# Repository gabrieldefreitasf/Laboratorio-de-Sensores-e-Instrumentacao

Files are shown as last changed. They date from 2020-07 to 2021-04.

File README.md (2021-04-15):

# Laboratorio-de-Sensores-e-Instrumentacao(LSI)
Repositório para códigos e arquivos de projeto referentes ao reflectômetro automatizado.<br>
Aqui estão códigos para ESP32 DevKit V1 escritos em framework Arduino para módulo de aquisição e controle do reflectômetro automatizado do LSI.<br>
Estão aqui os códigos separados por aquisição, movimento 2D, rotação e emulador para envio de dados.
Um código em python denominado ESP 32 - Datalogger é utilizado para gerar um arquivo com dados provenientes da serial.<br>
**Projeto desenvolvido no Laboratório de Sensores e Instrumentação do Departamento de Eletrônica e Sistemas da UFPE.**<br>
<br>
<br>
**Laboratory of Sensors and Instrumentation**<br>
Repository for codes and design files for the automated reflectometer.<br>
Here are the codes for ESP32 written in Arduino framework for LSI's automated reflectometer acquisition and control module.<br>
The codes are separated by acquisition, 2D movement, rotation and an emulator, for sending simulated data.<br>
A python code called ESP 32 - Datalogger is used to generate a file with data from the serial.<br>
**Project developed in the Laboratory of Sensors and Instrumentation under the Department of Electronics and Systems from UFPE.**<br>
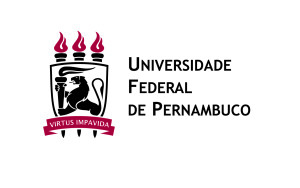
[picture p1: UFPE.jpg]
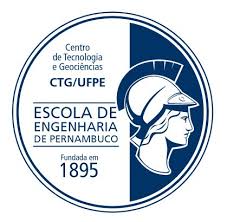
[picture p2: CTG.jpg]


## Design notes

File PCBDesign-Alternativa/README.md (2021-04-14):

Este diretório abriga os arquivos de projeto para placa de circuito impresso do reflectômetro automatizado. Os arquivos foram gerados em plataforma KiCAD.
--------------------------------
This directory contains the design files for the printed circuit board for the automated reflectometer. The files were generated on KiCAD platform.

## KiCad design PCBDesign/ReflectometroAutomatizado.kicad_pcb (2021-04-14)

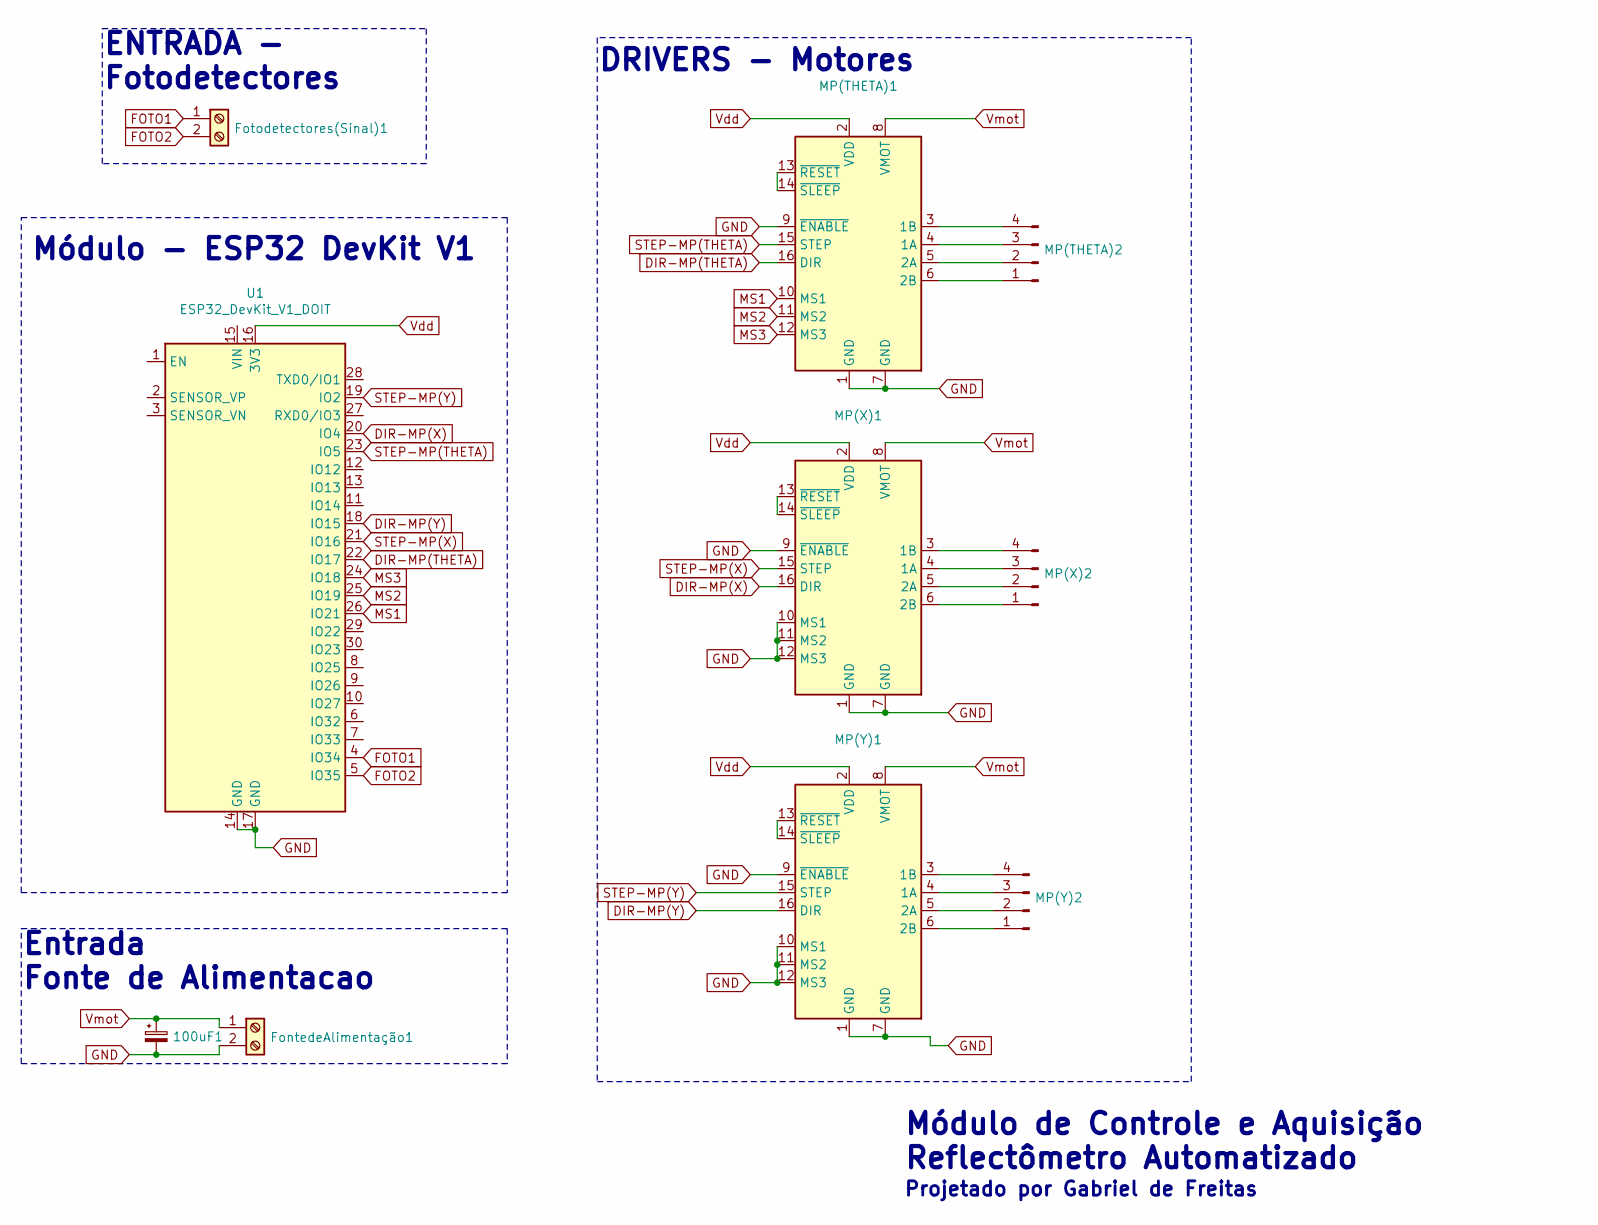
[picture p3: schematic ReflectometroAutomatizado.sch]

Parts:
100uF1: CP_Small; CP_Radial_D5.0mm_P2.00mm
FontedeAlimentação1: Screw_Terminal_01x02; TerminalBlock_bornier-2_P5.08mm
Fotodetectores(Sinal)1: Screw_Terminal_01x02; TerminalBlock_bornier-2_P5.08mm
MP(THETA)1: Pololu_Breakout_A4988; MODULE_A4988
MP(THETA)2: Conn_01x04_Male; PinHeader_1x04_P2.54mm_Vertical
MP(X)1: Pololu_Breakout_A4988; MODULE_A4988
MP(X)2: Conn_01x04_Male; PinHeader_1x04_P2.54mm_Vertical
MP(Y)1: Pololu_Breakout_A4988; MODULE_A4988
MP(Y)2: Conn_01x04_Male; PinHeader_1x04_P2.54mm_Vertical
U1: ESP32_DevKit_V1_DOIT; esp32_devkit_v1_doit

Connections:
DIR-MP(THETA): MP(THETA)1.16 (DIR), U1.22 (IO17)
DIR-MP(X): MP(X)1.16 (DIR), U1.20 (IO4)
DIR-MP(Y): MP(Y)1.16 (DIR), U1.18 (IO15)
FOTO1: Fotodetectores(Sinal)1.1, U1.4 (IO34)
FOTO2: Fotodetectores(Sinal)1.2, U1.5 (IO35)
GND: 100uF1.2, FontedeAlimentação1.2, MP(THETA)1.1 (GND), MP(THETA)1.7 (GND), MP(THETA)1.9 (~ENABLE), MP(X)1.1 (GND), MP(X)1.7 (GND), MP(X)1.9 (~ENABLE), MP(X)1.10 (MS1), MP(X)1.11 (MS2), MP(X)1.12 (MS3), MP(Y)1.1 (GND), MP(Y)1.7 (GND), MP(Y)1.9 (~ENABLE), MP(Y)1.10 (MS1), MP(Y)1.11 (MS2), MP(Y)1.12 (MS3), U1.14 (GND), U1.17 (GND)
MS1: MP(THETA)1.10 (MS1), U1.26 (IO21)
MS2: MP(THETA)1.11 (MS2), U1.25 (IO19)
MS3: MP(THETA)1.12 (MS3), U1.24 (IO18)
unnamed: MP(THETA)1.3 (1B), MP(THETA)2.4
unnamed: MP(THETA)1.4 (1A), MP(THETA)2.3
unnamed: MP(THETA)1.5 (2A), MP(THETA)2.2
unnamed: MP(THETA)1.6 (2B), MP(THETA)2.1
unnamed: MP(THETA)1.13 (~RESET), MP(THETA)1.14 (~SLEEP)
unnamed: MP(X)1.3 (1B), MP(X)2.4
unnamed: MP(X)1.4 (1A), MP(X)2.3
unnamed: MP(X)1.5 (2A), MP(X)2.2
unnamed: MP(X)1.6 (2B), MP(X)2.1
unnamed: MP(X)1.13 (~RESET), MP(X)1.14 (~SLEEP)
unnamed: MP(Y)1.3 (1B), MP(Y)2.4
unnamed: MP(Y)1.4 (1A), MP(Y)2.3
unnamed: MP(Y)1.5 (2A), MP(Y)2.2
unnamed: MP(Y)1.6 (2B), MP(Y)2.1
unnamed: MP(Y)1.13 (~RESET), MP(Y)1.14 (~SLEEP)
STEP-MP(THETA): MP(THETA)1.15 (STEP), U1.23 (IO5)
STEP-MP(X): MP(X)1.15 (STEP), U1.21 (IO16)
STEP-MP(Y): MP(Y)1.15 (STEP), U1.19 (IO2)
Vdd: MP(THETA)1.2 (VDD), MP(X)1.2 (VDD), MP(Y)1.2 (VDD), U1.16 (3V3)
Vmot: 100uF1.1, FontedeAlimentação1.1, MP(THETA)1.8 (VMOT), MP(X)1.8 (VMOT), MP(Y)1.8 (VMOT)

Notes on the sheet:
DRIVERS - Motores
ENTRADA - Fotodetectores
Módulo - ESP32 DevKit V1
Entrada Fonte de Alimentacao
Módulo de Controle e Aquisição Reflectômetro Automatizado
Projetado por Gabriel de Freitas

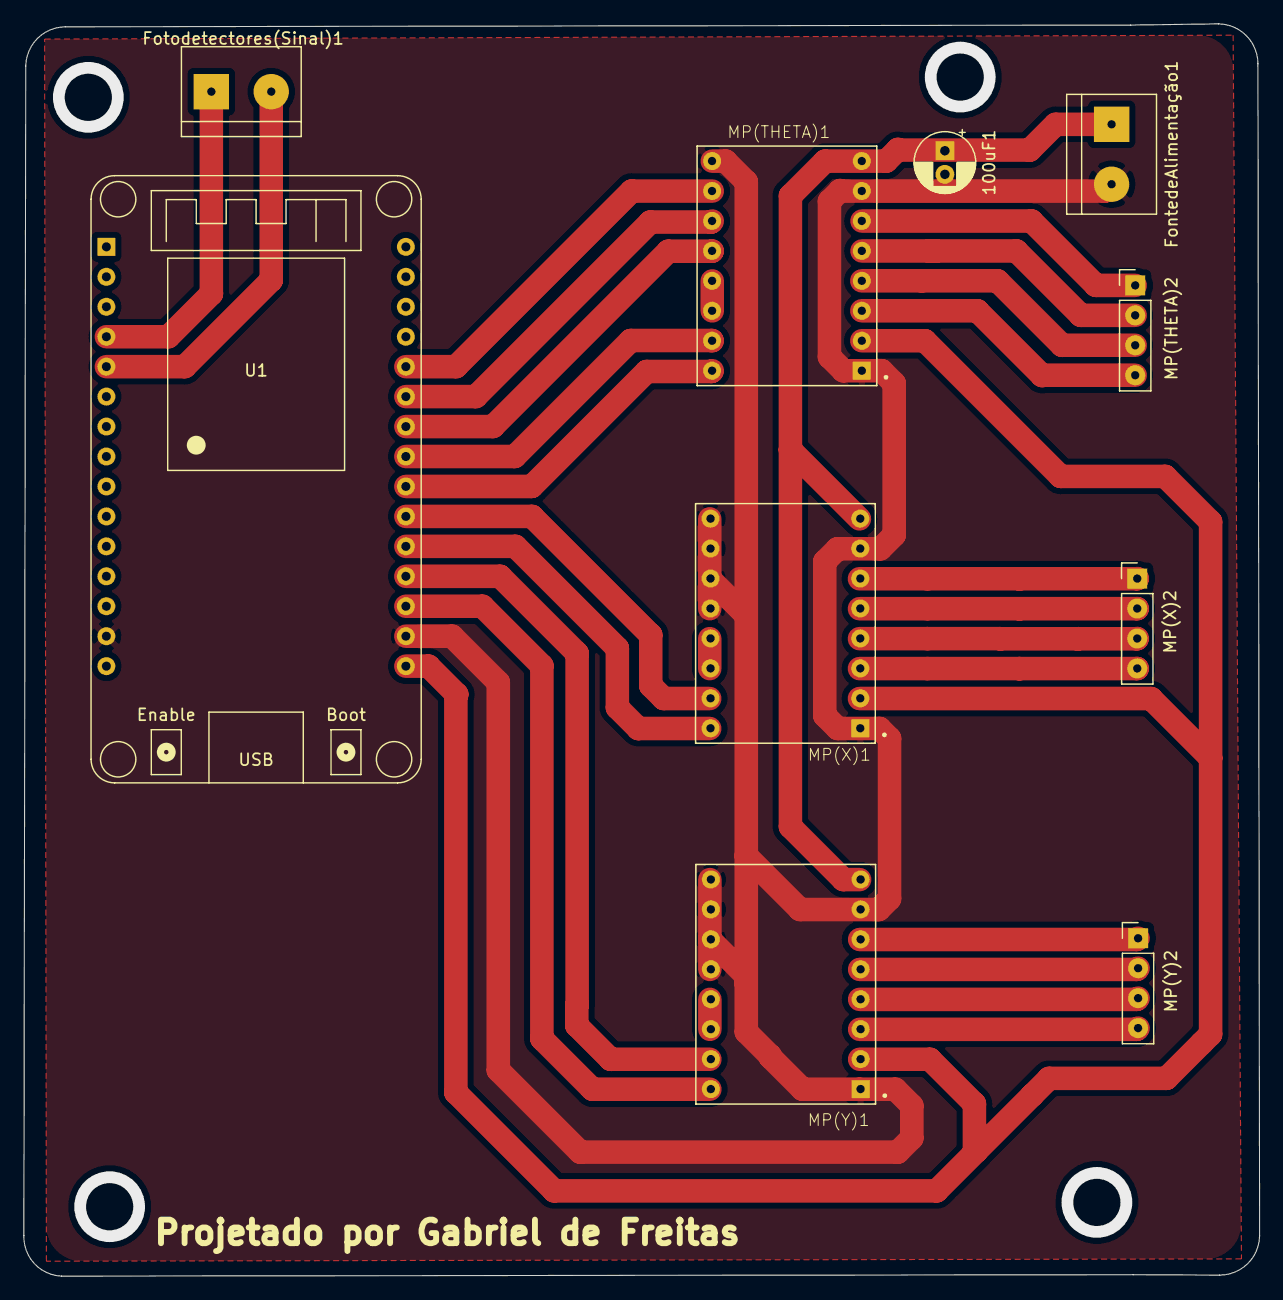
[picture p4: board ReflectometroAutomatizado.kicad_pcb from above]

Board: 2 copper layers, 104.8 x 106.2 mm, 10 parts (0 on the bottom side), 29 nets.

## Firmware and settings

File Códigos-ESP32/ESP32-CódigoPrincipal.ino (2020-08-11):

//Aquisição+Rotação+Movimento 2D - Código para ESP32, controle baseado em driver a4988
//Laboratório de Sensores e Instrumentação - Grupo de Fotônica - UFPE
//Gabriel de Freitas
//OBS: 6.163° / revolução. 1 passo rotaciona 0.061°
//OBS2: 0.011mm/passo
//OBS3: Cálculos executados são desenvolvidos no artigo: "Maintaining a stationary laser footprint during angular scan in internal-reflection experiments" - E. Fontana
//---------------------------------------------------
#include <math.h>
const int stepPin = 5;                               // Passo e direção para motor de movimento angular
const int dirPin = 17;
const int stepPinx = 16;
const int dirPinx = 4;
const int stepPiny = 2;
const int dirPiny = 15;
const int MS1 = 21;
const int MS2 = 19;
const int MS3 = 18;
// Declaração de Entradas Analógicas
const int foto1 = 34;                                   // Fotodetector de referência é conectado ao GPIO 34 (Analog ADC1_CH6)
const int foto2 = 35;                                   // Fotodetector de saída é conectado ao GPIO 35 (Analog ADC1_CH7)
//Fim das entradas analógicas
//Variáveis para aquisição de dados
int ValorFoto1 = 0;                                   //Variável para fotodetector de referência (foto1)
int ValorFoto2 = 0;                                   //Variável para fotodetector de saída (foto2)
int N;                                                //Número de médias para obtenção de um ponto na curva de reflectância
float R = 0;                                          //Valor médio de reflectância (Será plotado no gráfico)
float soma = 0;                                       //Variável auxiliar para cálculo de média
float reflect[2];                                     //Vetor para armazenar valores adquiridos de reflectância(Tem que ter o tamanho de N)
//Fim das variáveis para aquisição de dados
float pi = 3.14159;
// Definição de parâmetros do prisma
float alpha = pi/3;                                     //Ângulo em rad
float beta = pi/3;
float gama = pi/3;
float w = 0;                                            //Posição atual do feixe na face superior do prisma, inicialmente 0
float a = 50;                                           //Dimensões do prisma (em mm)
float b = 50;
float c = 50;
float n = 1.5;                                          //Índice de refração do prisma
//Fim da definição de parâmetros do prisma
//Definições de variáveis úteis para correção da posição do feixe (Proveniente do artigo)
float theta = 6;                                      //Ângulo a ser rotacionado
float theta_atual;                                      //Ângulo que o sistema está, essa variável vai ser usada para plotar o gráfico.
float l;                                                //Variável auxiliar no cálculo (pode ser excluída depois)
float d;                                                //Distância necessária transladar para manter feixe no mesmo ponto
float theta_r;                                          //Ângulo refratado. Útil no cálculo de d
float r;                                                //Raio da circunferência inscrita
//Fim das definições de variáveis
//Definição de variáveis para movimentação 2D
float esp = 2;                                     // Espaçamento entre células em mm
float x,y = 0;                                     // Posição em x e y em mm, sempre inicia-se em (0,0)
int celula;                                        // Célula que o reflectômetro deve se posicionar, receber valo de 0 a 120 do usuário
//Fim da definição de variáveis para movimentação 2D

void setup() 
{
  Serial.begin(115200);
  analogReadResolution(12);                             //Número de bits do ADC
  adcAttachPin(34);                                     //Selecionando pino 34 para ADC
  adcAttachPin(35);                                     //Selecionando pino 35 para ADC
  analogSetSamples(1);                                  //Selecionando número de amostras
  analogSetPinAttenuation(34,ADC_0db);                  //Seleciona atenuação de 0db no pino 34
  analogSetPinAttenuation(35,ADC_0db);                  //Seleciona atenuação de 0db no pino 35
  pinMode(5, OUTPUT);
  pinMode(17, OUTPUT);
  pinMode(16, OUTPUT);
  pinMode(4, OUTPUT);
  pinMode(2, OUTPUT);
  pinMode(15, OUTPUT);
  pinMode(21, OUTPUT);
  pinMode(19, OUTPUT);
  pinMode(18, OUTPUT);
  pinMode(34, INTPUT);
  pinMode(35, INTPUT);
}

void adquirir()                                         //Adquire um ponto de reflectância a partir de média de N pontos. 
{
  for (int i=0; i<N; i++)
  {
  ValorFoto1 = analogRead(foto1);                       //Lê valor do fotodetector de REFERÊNCIA
  adcBusy(34);                                          //Verifica se está ocorrendo conversão no pino 34, esse comando retorna verdadeiro ou falso
  ValorFoto2 = analogRead(foto2);                       //Lê valor do fotodetector de SAÍDA
  adcBusy(35);                                          //Verifica se está ocorrendo conversão no pino 34, esse comando retorna verdadeiro ou falso
  reflect[i] = ValorFoto2/ValorFoto1;
  soma = soma+ reflect[i];
  }
  R = soma/N;
  delayMicroseconds(500);
}

void rotacionar (float theta)
{
  if (theta<0){                                         //Verifica para qual lado deve rotacionar
  digitalWrite(dirPin, HIGH);                           //Rotaciona para região negativa(Esquerda)
  }
  else{
    digitalWrite(dirPin, LOW);                          //Rotaciona para região positiva (Direita)
  }
  if(abs(theta)<=0,003)                                       //Passo subdividido em 1/16
  {
    digitalWrite(MS1,HIGH);
    digitalWrite(MS2,HIGH);
    digitalWrite(MS3,HIGH);
  }
  if(abs(theta)>0,003 && abs(theta)<=0,007)                                       //Passo subdividido em 1/8
  {
    digitalWrite(MS1,HIGH);
    digitalWrite(MS2,HIGH);
    digitalWrite(MS3,LOW);
  }
  if(abs(theta)>0,007 && abs(theta)<=0,015)                                       //Passo subdividido em 1/4
  {
    digitalWrite(MS1,LOW);
    digitalWrite(MS2,HIGH);
    digitalWrite(MS3,LOW); 
  }
  if(abs(theta)>0,015 && abs(theta)<=0,03)                                        //Passo subdividido em 1/2
  {
    digitalWrite(MS1,HIGH);
    digitalWrite(MS2,LOW);
    digitalWrite(MS3,LOW);
  }
  else                                                  //Passo completo
  {
    digitalWrite(MS1, LOW);
    digitalWrite(MS2, LOW);
    digitalWrite(MS3, LOW);
  }
  for(int i = 0; i < (int)(theta/0,061); i++)           //Dá o número de passos relacionado ao ângulo a ser rotacionado - Atenção para a imprecisão nesse for
  {
    digitalWrite(stepPin,HIGH);
    delayMicroseconds(500);
    digitalWrite(stepPin,LOW);
    delayMicroseconds(500);
  }
  
  l = a*sin(beta/2)*cos(alpha/2)/sin((alpha+beta)/2);
  r = a/(cos(alpha/2)/sin(alpha/2) + cos(beta/2)/sin(beta/2));
  theta_r = asin(sin(theta)/n);
  d = -w + (1/cos(alpha+theta))*(2*sin(theta/2)*((-l+a/2)*sin(alpha+theta/2)+r*cos(alpha+theta/2)) - (w+alpha/2)*sin(alpha)*sin(theta - theta_r)/cos(theta_r));

  if (d<0)                                             //Verifica se translada no sentido +x ou -x (VERIFICAR ISSO NO MOTOR)
  {                   
    digitalWrite(dirPinx, HIGH);                       //Translada para região negativa(Esquerda)
  }
  else{
    digitalWrite(dirPinx, LOW);                        //Translada para região positiva (Direita)
  }
  for (int i=0; i < (int)(d/0,011); i++)               //Dá o número de passos relacionado a distância a ser transladada em mm
  {
    digitalWrite(stepPinx, HIGH);
    delayMicroseconds(500);
    digitalWrite(stepPinx,LOW);
    delayMicroseconds(500);
  }
  theta_atual = theta_atual+theta;
   x = x+d;
}

void ir_para(int celula) {
  
  switch(celula){
    case 120:
    {
    float posicao120_x = -5*esp;
    float posicao120_y = 5*esp;

    if ((posicao120_x - x) < 0){                     // Verifica se o movimento é no sentido +x ou -x (CHECAR NA MONTAGEM EXPERIMENTAL)
      digitalWrite(dirPinx, HIGH);
    }
    else{
      digitalWrite(dirPinx, LOW);
    }
    
    for(int i=0; i < abs(posicao120_x - x)/0,011; i++){    // Move, em x, o necessário para chegar na posição pré definida da célula
      digitalWrite(stepPinx, HIGH);
      delayMicroseconds(500);
      digitalWrite(stepPinx, LOW);
      delayMicroseconds(500);
    }
    
    if ((posicao120_y - y) < 0){                     // Repete o processo para y
      digitalWrite(dirPiny, HIGH);
    }
    else{
      digitalWrite(dirPiny, LOW);
    }
    
    for(int i=0; i < abs(posicao120_y - y)/0,011; i++){
      digitalWrite(stepPiny, HIGH);
      delayMicroseconds(500);
      digitalWrite(stepPiny, LOW);
      delayMicroseconds(500);
    }
    x = posicao120_x;                            // Atualiza a posição em x e y
    y = posicao120_y;
    }
    break;
    case 119:
    {
    float posicao119_x = -4*esp;
    float posicao119_y = 5*esp;

    if ((posicao119_x - x) < 0){                     // Verifica se o movimento é no sentido +x ou -x (CHECAR NA MONTAGEM EXPERIMENTAL)
      digitalWrite(dirPinx, HIGH);
    }
    else{
      digitalWrite(dirPinx, LOW);
    }
    
    for(int i=0; i < abs(posicao119_x - x)/0,011; i++){    // Move, em x, o necessário para chegar na posição pré definida da célula
      digitalWrite(stepPinx, HIGH);
      delayMicroseconds(500);
      digitalWrite(stepPinx, LOW);
      delayMicroseconds(500);
    }
    
    if ((posicao119_y - y) < 0){                     // Repete o processo para y
      digitalWrite(dirPiny, HIGH);
    }
    else{
      digitalWrite(dirPiny, LOW);
    }
    
    for(int i=0; i < abs(posicao119_y - y)/0,011; i++){
      digitalWrite(stepPiny, HIGH);
      delayMicroseconds(500);
      digitalWrite(stepPiny, LOW);
      delayMicroseconds(500);
    }
    x = posicao119_x;                            // Atualiza a posição em x e y
    y = posicao119_y;
    }
    break;
    case 118:
    {
    float posicao118_x = -3*esp;
    float posicao118_y = 5*esp;

    if ((posicao118_x - x) < 0){                     // Verifica se o movimento é no sentido +x ou -x (CHECAR NA MONTAGEM EXPERIMENTAL)
      digitalWrite(dirPinx, HIGH);
    }
    else{
      digitalWrite(dirPinx, LOW);
    }
    
    for(int i=0; i < abs(posicao118_x - x)/0,011; i++){    // Move, em x, o necessário para chegar na posição pré definida da célula
      digitalWrite(stepPinx, HIGH);
      delayMicroseconds(500);
      digitalWrite(stepPinx, LOW);
      delayMicroseconds(500);
    }
    
    if ((posicao118_y - y) < 0){                     // Repete o processo para y
      digitalWrite(dirPiny, HIGH);
    }
    else{
      digitalWrite(dirPiny, LOW);
    }
    
    for(int i=0; i < abs(posicao118_y - y)/0,011; i++){
      digitalWrite(stepPiny, HIGH);
      delayMicroseconds(500);
      digitalWrite(stepPiny, LOW);
      delayMicroseconds(500);
    }
    x = posicao118_x;                            // Atualiza a posição em x e y
    y = posicao118_y;
    }
    break;
    case 117:
    {
    float posicao117_x = -2*esp;
    float posicao117_y = 5*esp;

    if ((posicao117_x - x) < 0){                     // Verifica se o movimento é no sentido +x ou -x (CHECAR NA MONTAGEM EXPERIMENTAL)
      digitalWrite(dirPinx, HIGH);
    }
    else{
      digitalWrite(dirPinx, LOW);
    }
    
    for(int i=0; i < abs(posicao117_x - x)/0,011; i++){    // Move, em x, o necessário para chegar na posição pré definida da célula
      digitalWrite(stepPinx, HIGH);
      delayMicroseconds(500);
      digitalWrite(stepPinx, LOW);
      delayMicroseconds(500);
    }
    
    if ((posicao117_y - y) < 0){                     // Repete o processo para y
      digitalWrite(dirPiny, HIGH);
    }
    else{
      digitalWrite(dirPiny, LOW);
    }
    
    for(int i=0; i < abs(posicao117_y - y)/0,011; i++){
      digitalWrite(stepPiny, HIGH);
      delayMicroseconds(500);
      digitalWrite(stepPiny, LOW);
      delayMicroseconds(500);
    }
    x = posicao117_x;                            // Atualiza a posição em x e y
    y = posicao117_y;
    }
    break;
    case 116:
    {
    float posicao116_x = -esp;
    float posicao116_y = 5*esp;

    if ((posicao116_x - x) < 0){                     // Verifica se o movimento é no sentido +x ou -x (CHECAR NA MONTAGEM EXPERIMENTAL)
      digitalWrite(dirPinx, HIGH);
    }
    else{
      digitalWrite(dirPinx, LOW);
    }
    
    for(int i=0; i < abs(posicao116_x - x)/0,011; i++){    // Move, em x, o necessário para chegar na posição pré definida da célula
      digitalWrite(stepPinx, HIGH);
      delayMicroseconds(500);
      digitalWrite(stepPinx, LOW);
      delayMicroseconds(500);
    }
    
    if ((posicao116_y - y) < 0){                     // Repete o processo para y
      digitalWrite(dirPiny, HIGH);
    }
    else{
      digitalWrite(dirPiny, LOW);
    }
    
    for(int i=0; i < abs(posicao116_y - y)/0,011; i++){
      digitalWrite(stepPiny, HIGH);
      delayMicroseconds(500);
      digitalWrite(stepPiny, LOW);
      delayMicroseconds(500);
    }
    x = posicao116_x;                            // Atualiza a posição em x e y
    y = posicao116_y;
    }
    break;
    case 115:
    {
    float posicao115_x = 0;
    float posicao115_y = 5*esp;

    if ((posicao115_x - x) < 0){                     // Verifica se o movimento é no sentido +x ou -x (CHECAR NA MONTAGEM EXPERIMENTAL)
      digitalWrite(dirPinx, HIGH);
    }
    else{
      digitalWrite(dirPinx, LOW);
    }
    
    for(int i=0; i < abs(posicao115_x - x)/0,011; i++){    // Move, em x, o necessário para chegar na posição pré definida da célula
      digitalWrite(stepPinx, HIGH);
      delayMicroseconds(500);
      digitalWrite(stepPinx, LOW);
      delayMicroseconds(500);
    }
    
    if ((posicao115_y - y) < 0){                     // Repete o processo para y
      digitalWrite(dirPiny, HIGH);
    }
    else{
      digitalWrite(dirPiny, LOW);
    }
    
    for(int i=0; i < abs(posicao115_y - y)/0,011; i++){
      digitalWrite(stepPiny, HIGH);
      delayMicroseconds(500);
      digitalWrite(stepPiny, LOW);
      delayMicroseconds(500);
    }
    x = posicao115_x;                            // Atualiza a posição em x e y
    y = posicao115_y;
    }
    break;
    case 114:
    {
    float posicao114_x = esp;
    float posicao114_y = 5*esp;

    if ((posicao114_x - x) < 0){                     // Verifica se o movimento é no sentido +x ou -x (CHECAR NA MONTAGEM EXPERIMENTAL)
      digitalWrite(dirPinx, HIGH);
    }
    else{
      digitalWrite(dirPinx, LOW);
    }
    
    for(int i=0; i < abs(posicao114_x - x)/0,011; i++){    // Move, em x, o necessário para chegar na posição pré definida da célula
      digitalWrite(stepPinx, HIGH);
      delayMicroseconds(500);
      digitalWrite(stepPinx, LOW);
      delayMicroseconds(500);
    }
    
    if ((posicao114_y - y) < 0){                     // Repete o processo para y
      digitalWrite(dirPiny, HIGH);
    }
    else{
      digitalWrite(dirPiny, LOW);
    }
    
    for(int i=0; i < abs(posicao114_y - y)/0,011; i++){
      digitalWrite(stepPiny, HIGH);
      delayMicroseconds(500);
      digitalWrite(stepPiny, LOW);
      delayMicroseconds(500);
    }
    x = posicao114_x;                            // Atualiza a posição em x e y
    y = posicao114_y;
    }
    break;
    case 113:
    {
    float posicao113_x = 2*esp;
    float posicao113_y = 5*esp;

    if ((posicao113_x - x) < 0){                     // Verifica se o movimento é no sentido +x ou -x (CHECAR NA MONTAGEM EXPERIMENTAL)
      digitalWrite(dirPinx, HIGH);
    }
    else{
      digitalWrite(dirPinx, LOW);
    }
    
    for(int i=0; i < abs(posicao113_x - x)/0,011; i++){    // Move, em x, o necessário para chegar na posição pré definida da célula
      digitalWrite(stepPinx, HIGH);
      delayMicroseconds(500);
      digitalWrite(stepPinx, LOW);
      delayMicroseconds(500);
    }
    
    if ((posicao113_y - y) < 0){                     // Repete o processo para y
      digitalWrite(dirPiny, HIGH);
    }
    else{
      digitalWrite(dirPiny, LOW);
    }
    
    for(int i=0; i < abs(posicao113_y - y)/0,011; i++){
      digitalWrite(stepPiny, HIGH);
      delayMicroseconds(500);
      digitalWrite(stepPiny, LOW);
      delayMicroseconds(500);
    }
    x = posicao113_x;                            // Atualiza a posição em x e y
    y = posicao113_y;
    }
    break;
    case 112:
    {
    float posicao112_x = 3*esp;
    float posicao112_y = 5*esp;

    if ((posicao112_x - x) < 0){                     // Verifica se o movimento é no sentido +x ou -x (CHECAR NA MONTAGEM EXPERIMENTAL)
      digitalWrite(dirPinx, HIGH);
    }
    else{
      digitalWrite(dirPinx, LOW);
    }
    
    for(int i=0; i < abs(posicao112_x - x)/0,011; i++){    // Move, em x, o necessário para chegar na posição pré definida da célula
      digitalWrite(stepPinx, HIGH);
      delayMicroseconds(500);
      digitalWrite(stepPinx, LOW);
      delayMicroseconds(500);
    }
    
    if ((posicao112_y - y) < 0){                     // Repete o processo para y
      digitalWrite(dirPiny, HIGH);
    }
    else{
      digitalWrite(dirPiny, LOW);
    }
    
    for(int i=0; i < abs(posicao112_y - y)/0,011; i++){
      digitalWrite(stepPiny, HIGH);
      delayMicroseconds(500);
      digitalWrite(stepPiny, LOW);
      delayMicroseconds(500);
    }
    x = posicao112_x;                            // Atualiza a posição em x e y
    y = posicao112_y;
    }
    break;
    case 111:
    {
    float posicao111_x = 4*esp;
    float posicao111_y = 5*esp;

    if ((posicao111_x - x) < 0){                     // Verifica se o movimento é no sentido +x ou -x (CHECAR NA MONTAGEM EXPERIMENTAL)
      digitalWrite(dirPinx, HIGH);
    }
    else{
      digitalWrite(dirPinx, LOW);
    }
    
    for(int i=0; i < abs(posicao111_x - x)/0,011; i++){    // Move, em x, o necessário para chegar na posição pré definida da célula
      digitalWrite(stepPinx, HIGH);
      delayMicroseconds(500);
      digitalWrite(stepPinx, LOW);
      delayMicroseconds(500);
    }
    
    if ((posicao111_y - y) < 0){                     // Repete o processo para y
      digitalWrite(dirPiny, HIGH);
    }
    else{
      digitalWrite(dirPiny, LOW);
    }
    
    for(int i=0; i < abs(posicao111_y - y)/0,011; i++){
      digitalWrite(stepPiny, HIGH);
      delayMicroseconds(500);
      digitalWrite(stepPiny, LOW);
      delayMicroseconds(500);
    }
    x = posicao111_x;                            // Atualiza a posição em x e y
    y = posicao111_y;
    }
    break;
    case 110:
    {
    float posicao110_x = 5*esp;
    float posicao110_y = 5*esp;

    if ((posicao110_x - x) < 0){                     // Verifica se o movimento é no sentido +x ou -x (CHECAR NA MONTAGEM EXPERIMENTAL)
      digitalWrite(dirPinx, HIGH);
    }
    else{
      digitalWrite(dirPinx, LOW);
    }
    
    for(int i=0; i < abs(posicao110_x - x)/0,011; i++){    // Move, em x, o necessário para chegar na posição pré definida da célula
      digitalWrite(stepPinx, HIGH);
      delayMicroseconds(500);
      digitalWrite(stepPinx, LOW);
      delayMicroseconds(500);
    }
    
    if ((posicao110_y - y) < 0){                     // Repete o processo para y
      digitalWrite(dirPiny, HIGH);
    }
    else{
      digitalWrite(dirPiny, LOW);
    }
    
    for(int i=0; i < abs(posicao110_y - y)/0,011; i++){
      digitalWrite(stepPiny, HIGH);
      delayMicroseconds(500);
      digitalWrite(stepPiny, LOW);
      delayMicroseconds(500);
    }
    x = posicao110_x;                            // Atualiza a posição em x e y
    y = posicao110_y;
    }
    break;
    case 109:
    {
    float posicao109_x = -5*esp;
    float posicao109_y = 4*esp;

    if ((posicao109_x - x) < 0){                     // Verifica se o movimento é no sentido +x ou -x (CHECAR NA MONTAGEM EXPERIMENTAL)
      digitalWrite(dirPinx, HIGH);
    }
    else{
      digitalWrite(dirPinx, LOW);
    }
    
    for(int i=0; i < abs(posicao109_x - x)/0,011; i++){    // Move, em x, o necessário para chegar na posição pré definida da célula
      digitalWrite(stepPinx, HIGH);
      delayMicroseconds(500);
      digitalWrite(stepPinx, LOW);
      delayMicroseconds(500);
    }
    
    if ((posicao109_y - y) < 0){                     // Repete o processo para y
      digitalWrite(dirPiny, HIGH);
    }
    else{
      digitalWrite(dirPiny, LOW);
    }
    
    for(int i=0; i < abs(posicao109_y - y)/0,011; i++){
      digitalWrite(stepPiny, HIGH);
      delayMicroseconds(500);
      digitalWrite(stepPiny, LOW);
      delayMicroseconds(500);
    }
    x = posicao109_x;                            // Atualiza a posição em x e y
    y = posicao109_y;
    }
    break;
    case 108:
    {
    float posicao108_x = -4*esp;
    float posicao108_y = 4*esp;
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
void loop()
{
  for(int i = 0;i<90;i++){                           //i<(numero de pontos no experimento)
  adquirir();
  rotacionar(theta);
  char char_theta;
  char char_R;
  dtostrf(theta_atual,7,3,char_theta);                //Dado de angulo tem 5 caracteres (ex: 40,061) e 3 casas decimais
  dtostrf(R,8,4,char_R);
  char dados[17] = {'char_theta',';','char_R'};       //Envia uma string com valor de angulo e reflectancia separados por ; (ex: 40,061;0,5647)
  //delay(5000);
  Serial.println(dados);
  }
  //Aqui é preciso usar uma interrupção
}

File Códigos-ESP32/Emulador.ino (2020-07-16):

// Emulador de Reflectômetro (Dados Seriais)
// Laboratório de Sensores e Instrumentação - Grupo de Fotônica - UFPE
// Gabriel de Freitas
//---------------------------------------------------
void setup() {
  Serial.begin(115200);
}

void loop() {
  float theta = 45.0615 + random(-5,5);
  float r = 0.75 + random(-1,1);
  Serial.print(theta);
  Serial.print(";");
  Serial.println(r);
  delay(10000);
}

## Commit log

2020-01-14 Add files via upload
    Código de aquisição de dados analógicos para ESP32.
2020-01-16 Update ESP32-Aquisicao.ino
    Excluída uma variável auxiliar sem utilidade
2020-01-18 Update ESP32-Rotacao.ino
    Reorganização da função setup e definição de parâmetros do prisma
2020-01-21 Update ESP32-Rotacao.ino
    Adição de cálculo de variáveis para translação necessária para manter o feixe no mesmo ponto e implementação da tal translação.
2020-02-03 Update ESP32-Aquisicao.ino
    Um delay retirado. Com isso, essa versão é, provavelmente, a final para a aquisição de dados podendo sofrer pequenas mudanças de adequação.
2020-02-12 Update ESP32-Rotacao.ino
    Casting adicionado nos dois laços for
2020-02-18 Update ESP32-Rotacao.ino
    Adição da variável theta_atual. Essa variável guarda o ângulo em que o sistema está e vai ser usada para construção do gráfico da reflectância em função do ângulo.
2020-02-18 Create CódigoPrincipal.ino
    Código que será a rotina principal executada pela ESP32. Por hora, constam as etapas de aquisição e rotação.
2020-02-18 Rename CódigoPrincipal.ino to ESP32-CódigoPrincipal.ino
    Padronizando o nome do arquivo.
2020-03-13 Update ESP32-Rotacao.ino
    Modificação nas portas por questão de praticidade das conexões. Adição de valores númericos nos parâmetros do prisma.
2020-03-13 Update ESP32-CódigoPrincipal.ino
    Modificação de portas por fins de praticidade de conexões. Atribuição de valores nos parâmetros do prisma.
2020-04-01 Código para movimento 2D baseado em driver a4988.
    Código recebe célula do usuário, movimenta bidimensionalmente e atualiza a posição. Essa versão inicial está implementado o movimento para a célula 60 apenas.
2020-04-02 Célula 59
    Adicionada rotina para movimentação até a célula 59
2020-04-02 Declaração de células 55 a 76.
    Montando a matriz apenas declarando as variáveis de posição por enquanto, para ter idéia da memória necessária sem gastar muito tempo. As células aqui declaradas correspondem às linhas 19 e 18 desse 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
2020-04-03 Declaração das células 99 à 120.
    Descritas as posições para as células que constam nas linhas 15 e 14 desse código.
2020-04-04 Declaração das células 0 a 21
    Linhas 23 e 24 desse código. Observando que o uso de memória em percentual para declarar duas variáveis float para cada célula não foi grande, vou manter essa idéia do código. Rotina para movimentaçã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
2020-04-07 Modificação de erros de cálculo
    Correção do sinal do valor de translação e adição do valor absoluto no for de movimentação dos motores.
2020-04-07 Correção nos for de movimentação dos motores
    Adição da função abs nos for de movimentação.
2020-04-07 Rotina de movimento para células 55 a 76
    Adicionado código para movimentação para células que constam nas linhas 20 e 21 desse código.
2020-04-08 Correção dos for de movimentação
    Havia um erro simples com os parenteses.
2020-04-08 Código de movimento para as células 77 à 87
    Linha 19 desse código.
2020-04-09 Código movimentação para células 88 a 98
    Linha 8
2020-04-09 Código de movimentação para células 99 a 109
    Linha 17
2020-04-09 Código de movimentação para células 110 a 120
    Linha 16
2020-04-10 Código de movimentação para as células 33 a 54
    Linhas 22 e 23.
2020-04-10 Código para movimentação das células 0 à 32
    Linhas 24, 25 e 26.
2020-04-10 Adição da função de movimento 2D
    Função void ir_para(int celula)
2020-04-19 Update ESP32-CódigoPrincipal.ino
    - Alteração dos ângulo internos do prisma alpha,beta,gama=60°
    rotacionar()
    - Intervalos de subdivisão de passo
    - Atualização da variável x devido a correção
    ir_para()
    -Alteração de x=posicaoi_x-x -> x = posicaoi_x (idem y) i=120,119...
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2020-07-16 Emulador de Reflectômetro (Dados Seriais)
    Emula envio de dados do tipo "Ângulo;Reflectância" via serial. Esse código é útil para testar a geração de arquivos por python.
2020-07-27 Correção das funções matemáticas
    Cálculo de d estava incorreto. Argumento da função asin() deve estar entre [-pi/2;pi/2].
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2020-08-11 Uso da função pinMode
    Adicionado uso da função pinMode para garantir funcionamento da função digitalWrite.
2021-06-03 Uso da função abs()
    Uso da função abs() na comparação para subdivisão de passo.
2021-08-30 Atualização de valores de calibração
    Valores de calibração para MP(theta) e MP(x) foram atualizados.
2021-08-31 Correção de valores de calibração
    Valores anteriormente em graus e agora em radiano.
2021-09-03 Correção de funções for para passo de motor.
    As funções estavam com valores desatualizados de constantes de calibração.
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2021-12-13 Projeto da V2 da PCB
    Este projeto inclui controle de enable dos drivers e alimentação separada para cada motor.
    [ReflectometroAutomatizado.kicad_pcb, ReflectometroAutomatizado.sch]
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2022-02-21 Projeto da placa atualizada
    Projeto com enable e alimentação isolada para motores
